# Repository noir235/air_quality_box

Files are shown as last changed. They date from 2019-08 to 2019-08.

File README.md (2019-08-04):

# MQTT - Air Quality Box

The MQTT air quality box can measure different value of the air around the box. This values can help you to evaluate the air quality in your rooms.In my case, I have in each room one box to understand the environment in my appartment.

How do you get the values from the box: The box itself has no display to show the different values. The box is designed to send each value with the MQTT protocol to a server. The server should able to recieve them as MQTT broker and show you the value for example with an web user interface. I use the famous home assistant and it works great for me.

The following value are measured by the box:
- temperature
- humidity
- CO2
- CO
- NH3
- NO2
- PM 2.5 (dust)
- PM 10 (dust)

Components for MQTT - air quality box:
- ESP8266 nodemcu V3
- nodemcu base
- Grove multichannel gas sensor (CO, NH3, NO2 sensor)
- DHT22 (temperature und humidity sensor)
- MH-Z19 (CO2 sensor)
- SDS011 (PM2.5, PM10 dust sensor)
- power adapter 12V DC, 2A
- Small box or case

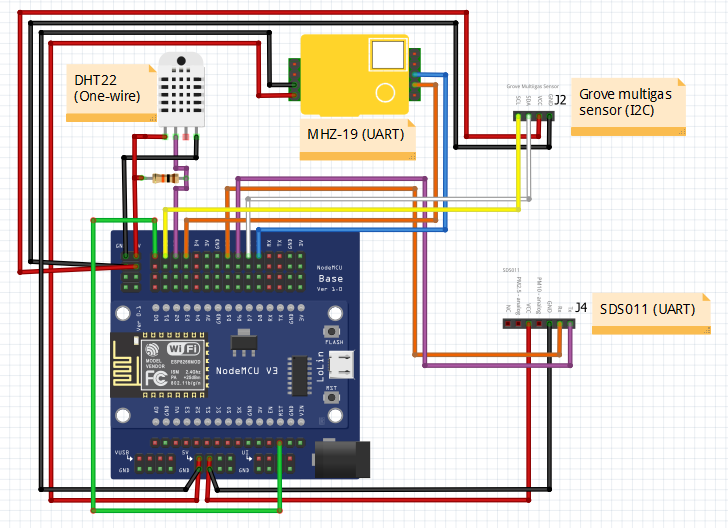
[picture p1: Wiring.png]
wiring picture


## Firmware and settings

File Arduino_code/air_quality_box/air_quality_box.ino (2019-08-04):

// Required libraries (sketch -> include library -> manage libraries)
// - PubSubClient by Nick ‘O Leary
// - DHT sensor library by Adafruit
// - SoftwareSerial by Peter Lerup
// - Grove-Multichannel gas sensor by Seed Studio
// - Nova Fitness SDS dust sensors arduino library by lewapek

//Libraries
#include <SoftwareSerial.h>
#include <ESP8266WiFi.h>
#include <PubSubClient.h>
#include <DHT.h>
#include <Wire.h>
#include "MutichannelGasSensor.h"
#include "SdsDustSensor.h"

//Data of your WIFI network
#define wifi_ssid "SSID of your WIFI"
#define wifi_password "WIFI password"

//MQTT Data of your server
#define mqtt_server "IP of your MQTT Broker"
#define mqtt_user "MQTT username"
#define mqtt_password "MQTT password"
#define client_no "Client ID"

//Definition of MQTT topics
#define humidity_topic "humidity"
#define temperature_topic "temperature"
#define CO2_topic "co2"
#define CO_topic "co"
#define NH3_topic "nh3"
#define NO2_topic "no2"
#define pm25_topic "pm25_value"
#define pm10_topic "pm10_value"

//Pins for sensor communications
#define DHTTYPE DHT22
#define DHTPIN  D2

#define MH_Z19_RX D3
#define MH_Z19_TX D8

#define PM_sensor_RX D5
#define PM_sensor_TX D6

//Variables for different sensor values
float temp = 0.0;
float hum = 0.0;
int CO2 = 0;
float CO_data = 0;
float NH3_data = 0;
float NO2_data = 0;

// Interval of sensor reading
long INTERVAL = 60; //INTERVAL [60s]
long INTERVAL_real = 0;

WiFiClient espClient;
PubSubClient client(espClient);

DHT dht(DHTPIN, DHTTYPE, 11); //define temperature and humidity sensor

SoftwareSerial co2Serial(MH_Z19_RX, MH_Z19_TX); // define MH-Z19
SoftwareSerial dustSerial(PM_sensor_RX, PM_sensor_TX); // define nova PM sensor
SdsDustSensor sds(dustSerial);

//Configuration of Wifi
void setup_wifi() {
  delay(10);
  // We start by connecting to a WiFi network
  WiFi.begin(wifi_ssid, wifi_password);
  //Loop until WiFi connected
  while (WiFi.status() != WL_CONNECTED) {
    delay(500);
  }
}

//Reading of CO2 sensor
int readCO2()
{

  byte cmd[9] = {0xFF, 0x01, 0x86, 0x00, 0x00, 0x00, 0x00, 0x00, 0x79};
  // command to ask for data
  char response[9]; // for answer

  co2Serial.write(cmd, 9); //request PPM CO2
  co2Serial.readBytes(response, 9);
  if (response[0] != 0xFF)
  {
    return -1;
  }

  if (response[1] != 0x86)
  {
    return -1;
  }

  int responseHigh = (int) response[2];
  int responseLow = (int) response[3];
  int newCO2 = (256 * responseHigh) + responseLow;
  return newCO2;
}

void setup() {
  Serial.begin(9600); //Init serial
  dht.begin(); //Init of communication with DHT22
  delay(100);
  Wire.begin(D7, D1); //Init one wire bus for communication with multichannel gas sensor
  gas.begin(0x04);//the default I2C address of the slave is 0x04
  gas.powerOn();
  setup_wifi(); //WiFi configuration
  client.setServer(mqtt_server, 1883); //Start communication with MQTT broker
  ESP.wdtDisable(); //Stop ESP software-watchdog
  ESP.wdtEnable(WDTO_8S); //Start ESP software-watchdog with time of 8 seconds
  delay(1000);
}

void loop() {
  INTERVAL_real = (INTERVAL * 1000000)-9000000; //Calculated time for depp sleep
  ESP.wdtFeed(); //Feed software-watchdog
  if (!client.connected()) //Analyze connection to MQTT broker. In case of no connection, try to reconnect.
  {
    while (!client.connected()) {
      if (client.connect(client_no, mqtt_user, mqtt_password)){
      }
      delay(500);
    }
  }
  client.loop(); //Prepare massaging with MQTT broker

  client.publish(client_no, "connected", true); //Client publish "connected"

  temp = dht.readTemperature(); //Measurement of temperaure
  if (isnan(temp)){
    while (isnan(temp)) {
      temp = dht.readTemperature();
      delay(500);
    }
  }
  ESP.wdtFeed(); //Feed software-watchdog
  hum = dht.readHumidity(); //Measurement of humidity
  if (isnan(hum)){
    while (isnan(hum)) {
      hum = dht.readHumidity();
      delay(500);
    }
  }
  ESP.wdtFeed(); //Feed software-watchdog
  delay(1000); //delay of 1s
  co2Serial.begin(9600); //Init sensor MH-Z19
  delay(1000); //delay of 1s
  CO2 = readCO2(); //Measurement of CO2
  delay(1000); //delay of 1s
  CO_data = gas.measure_CO(); //Measurement of CO
  co2Serial.end(); //End of serial connection to sensor MH-Z19
  ESP.wdtFeed(); //Feed software-watchdog
  delay(1000); //delay of 1s
  NH3_data = gas.measure_NH3(); //Measurement of NH3
  delay(1000); //delay of 1s
  NO2_data = gas.measure_NO2(); //Measurement of NO2
  sds.begin(); //Init Nova Fitness SDS dust sensors
  ESP.wdtFeed(); //Feed software-watchdog
  delay(1000); //delay of 1s
  PmResult pm = sds.readPm(); //Measurement of PM2.5 & PM10 and sending to MQTT broker
  if (pm.isOk()) {
    client.publish(pm25_topic, String(pm.pm25).c_str(), true);
    Serial.println("pm25 sent");
    delay(1000);
    client.publish(pm10_topic, String(pm.pm10).c_str(), true);
    Serial.println("pm10 sent");
    delay(1000);
  }
  if (temp > 0 && temp < 50) { //If temperature is between 0°C and 50°C, send the value to MQTT broker
    client.publish(temperature_topic, String(temp).c_str(), true);
    Serial.println("temp sent");
    ESP.wdtFeed();
    delay(1000);
  }
  if (hum > 20 && hum < 80) { //If humidity is between 20% and 80%, send the value to MQTT broker
    client.publish(humidity_topic, String(hum).c_str(), true);
    Serial.println("humid sent");
    ESP.wdtFeed();
    delay(1000);
  }
  if (CO2 > 200 && CO2 < 5000) { //If CO2 is between 200 and 5000, send the value to MQTT broker
    client.publish(CO2_topic, String(CO2).c_str(), true);
    Serial.println("co2 sent");
    ESP.wdtFeed();
    delay(1000);
  }
  if (CO_data > 0.01 && CO_data < 1300) {//If CO is between 0.01 and 1300, send the value to MQTT broker
    client.publish(CO_topic, String(CO_data).c_str(), true);
    Serial.println("CO sent");
    ESP.wdtFeed();
    delay(500);
  }
  if (NH3_data > 0.01 && NH3_data < 2000) {//If NH3 is between 0.01 and 2000, send the value to MQTT broker
    client.publish(NH3_topic, String(NH3_data).c_str(), true);
    Serial.println("NH3 sent");
    ESP.wdtFeed();
    delay(500);
  }
  if (NO2_data > 0.01 && NO2_data < 2000) {//If NO2 is between 0.01 and 2000, send the value to MQTT broker
    client.publish(NO2_topic, String(NO2_data).c_str(), true);
    Serial.println("NO2 sent");
    ESP.wdtFeed();
    delay(500);
  }
  client.disconnect(); //Disconnect from MQTT broker
  WiFi.disconnect(); //Disconnect from WiFi
  ESP.wdtFeed();
  ESP.deepSleep(INTERVAL_real); //Start of deep sleep
  delay(500);
}
